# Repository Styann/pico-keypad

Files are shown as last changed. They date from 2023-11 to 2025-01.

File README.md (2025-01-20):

# Anesidora

A 65% keyboard PCB for the Raspberry pi pico made with KiCad 8, and a custom firmware.

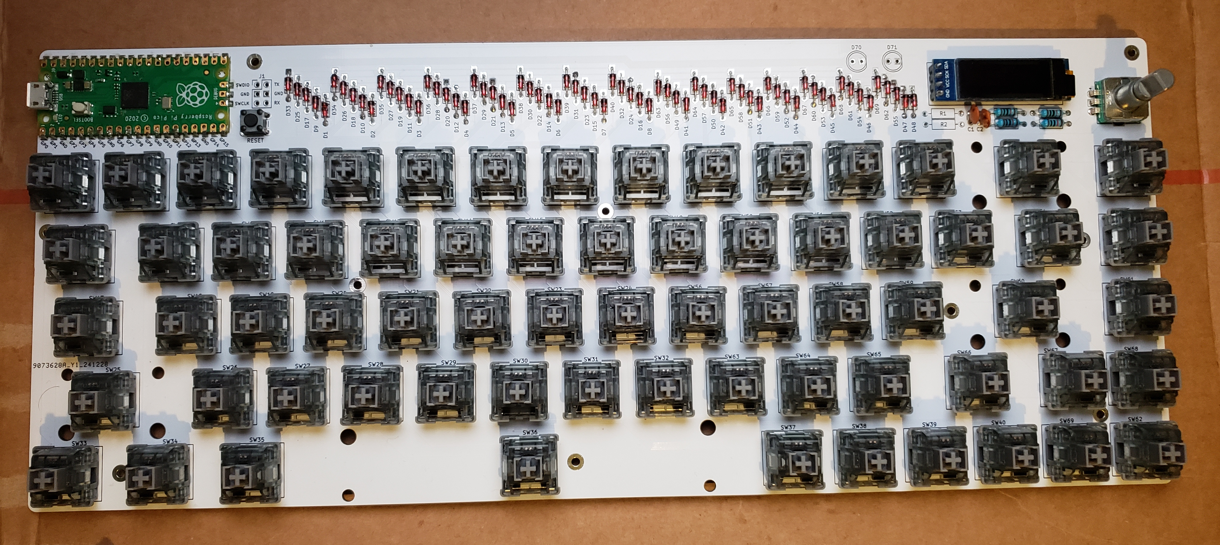
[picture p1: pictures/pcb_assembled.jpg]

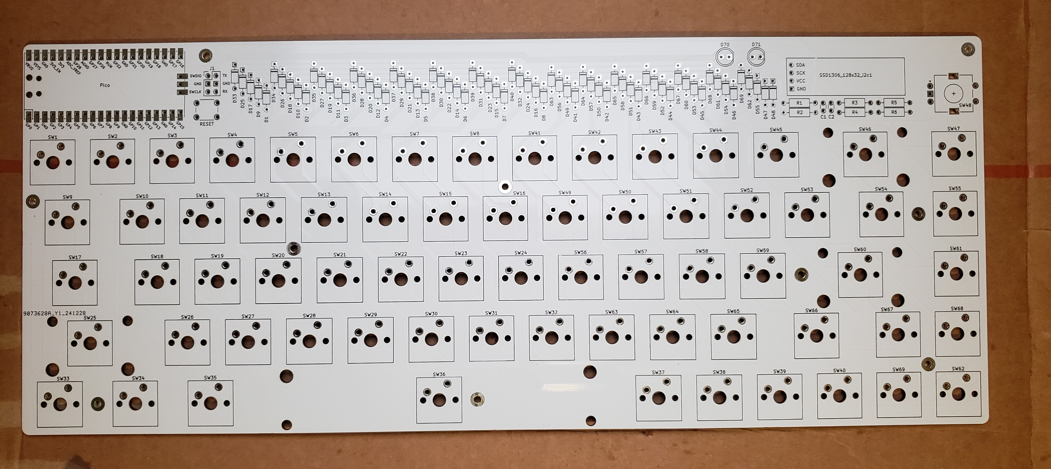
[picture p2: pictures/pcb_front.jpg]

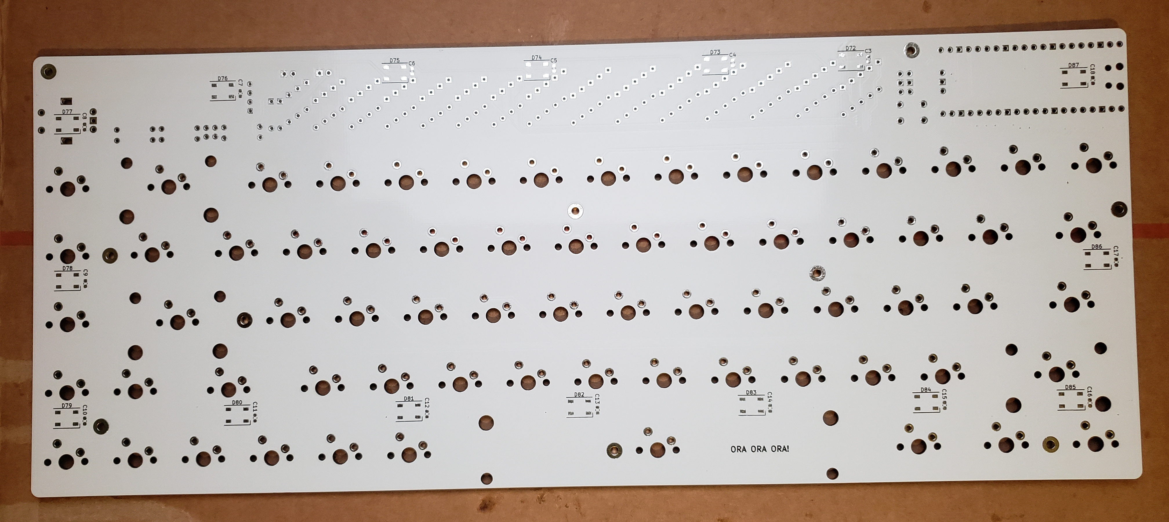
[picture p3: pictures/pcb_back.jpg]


## Assembly

### THT components
- Raspberry Pico
- Keyboard Switches (x68)
- Keyboard Stabilizers
- Rotary Encoder
- Resistors 10KOhm (x4)
- Capacitors 0.1µF (x2)
- Diodes 1N4148 (x69)
- SSD1306 OLED display 128x32
- LEDs (x2)
- Resistors (x2 for LEDs)
- Button
- 2.54mm Male Pin Header 2x6

### SMD components
- leds WS2812B (x16)
- SMD Capacitors 0603 100nF (x16)

## 📦 Build the firmware
1.
Install the pico C/C++ SDK (https://www.raspberrypi.com/documentation/microcontrollers/c_sdk.html)

2.
```sh
export ANESIDORA_PATH=path/to/Anesidora
```

3.
```sh
export PICO_USB_DISK_PATH=path/to/RPI-RP2
```

4.
```sh
./deploy.sh --build --flash
```

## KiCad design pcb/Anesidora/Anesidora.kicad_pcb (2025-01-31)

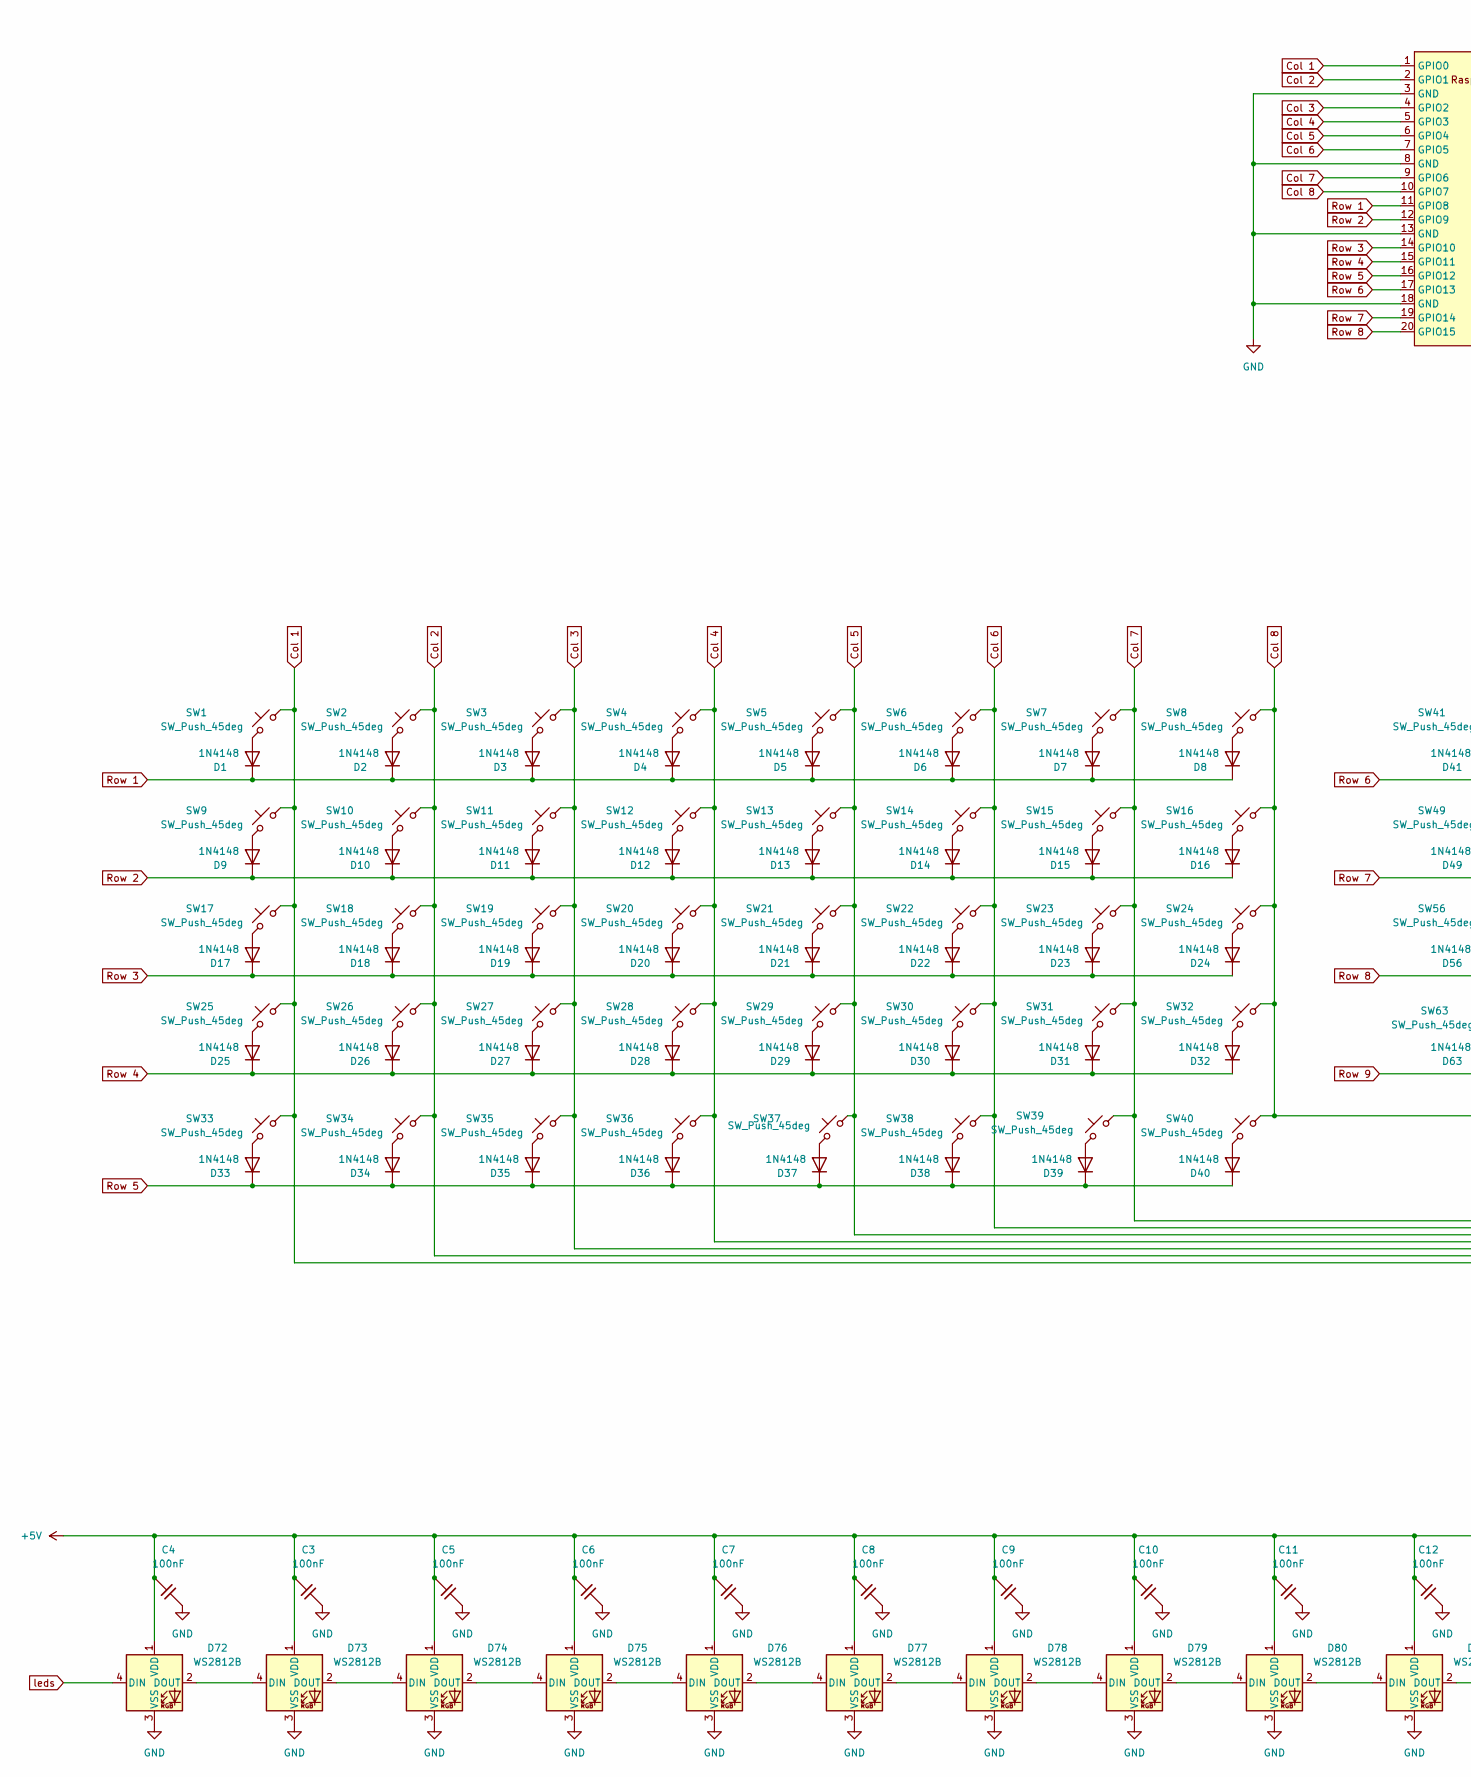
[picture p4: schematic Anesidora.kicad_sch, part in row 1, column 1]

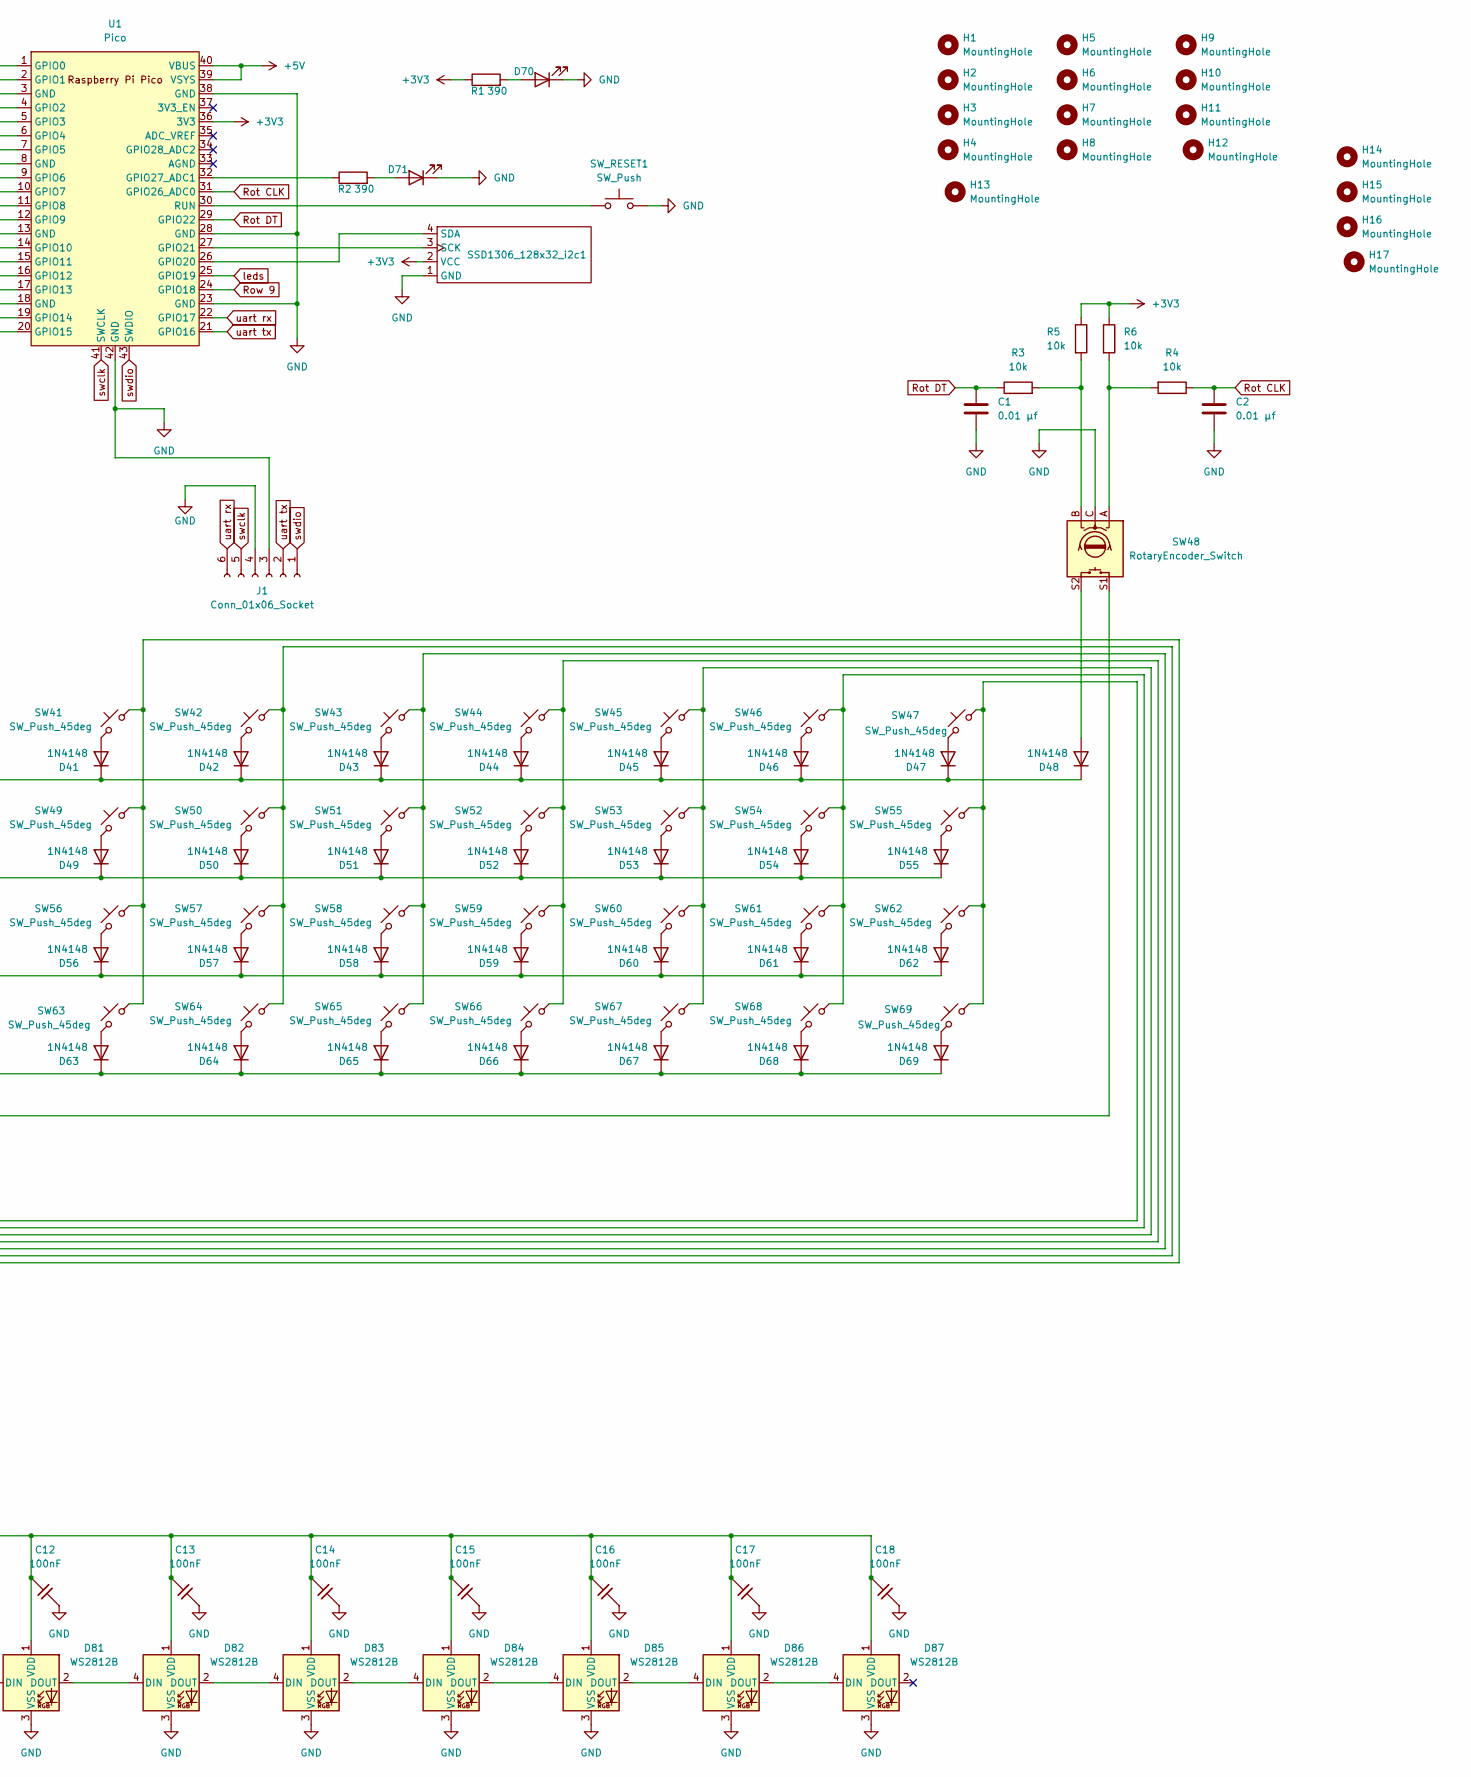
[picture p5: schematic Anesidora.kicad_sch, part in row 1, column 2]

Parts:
C1, C2: 0.01 µf; C_Disc_D3.0mm_W1.6mm_P2.50mm
C3, C4, C5, C6, C7, C8, C9, C10, C11, C12, C13, C14, C15, C16, C17, C18: 100nF; C_0603_1608Metric
D1, D2, D3, D4, D5, D6, D7, D8, D9, D10, D11, D12, D13, D14, D15, D16, D17, D18, D19, D20, D21, D22, D23, D24, D25, D26, D27, D28, D29, D30, D31, D32, D33, D34, D35, D36, D37, D38, D39, D40, D41, D42, D43, D44, D45, D46, D47, D48, D49, D50, D51, D52, D53, D54, D55, D56, D57, D58, D59, D60, D61, D62, D63, D64, D65, D66, D67, D68, D69: 1N4148; D_DO-35_SOD27_P7.62mm_Horizontal
D70, D71: LED; LED_D5.0mm
D72, D73, D74, D75, D76, D77, D78, D79, D80, D81, D82, D83, D84, D85, D86, D87: WS2812B; LED_WS2812B_PLCC4_5.0x5.0mm_P3.2mm
H1, H2, H3, H4, H5, H6, H7, H8, H9, H10, H11, H12, H13, H14, H15, H16, H17: MountingHole; MountingHole_2.2mm_M2_Pad
J1: Conn_01x06_Socket; PinHeader_2x03_P2.54mm_Vertical
R1, R2: 390; R_Axial_DIN0207_L6.3mm_D2.5mm_P10.16mm_Horizontal
R3, R4, R5, R6: 10k; R_Axial_DIN0207_L6.3mm_D2.5mm_P10.16mm_Horizontal
SSD1306_128x32_i2c1: SSD1306_128x32_i2c
SW1, SW2, SW3, SW4, SW5, SW6, SW7, SW8, SW10, SW11, SW12, SW13, SW14, SW15, SW16, SW18, SW19, SW20, SW21, SW22, SW23, SW24, SW26, SW27, SW28, SW29, SW30, SW31, SW32, SW37, SW38, SW39, SW40, SW41, SW42, SW43, SW44, SW45, SW47, SW49, SW50, SW51, SW52, SW53, SW55, SW56, SW57, SW58, SW59, SW61, SW62, SW63, SW64, SW65, SW67, SW68, SW69: SW_Push_45deg; SW_Cherry_MX_PCB_1.00u
SW9, SW54: SW_Push_45deg; SW_Cherry_MX_PCB_1.50u
SW17, SW66: SW_Push_45deg; SW_Cherry_MX_PCB_1.75u
SW25, SW60: SW_Push_45deg; SW_Cherry_MX_PCB_2.25u
SW33, SW34, SW35: SW_Push_45deg; SW_Cherry_MX_PCB_1.25u
SW36: SW_Push_45deg; SW_Cherry_MX_PCB_6.25u
SW46: SW_Push_45deg; SW_Cherry_MX_PCB_2.00u
SW48: RotaryEncoder_Switch; RotaryEncoder_Alps_EC11E-Switch_Vertical_H20mm
SW_RESET1: SW_Push; SW_PUSH_6mm
U1: Pico; RPi_Pico_SMD_TH

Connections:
+3V3: R1.1, R5.1, R6.1, SSD1306_128x32_i2c1.2 (VCC), U1.36 (3V3); also elsewhere on the board
+5V: C3.2, C4.2, C5.2, C6.2, C7.2, C8.2, C9.2, C10.2, C11.2, C12.2, C13.2, C14.2, C15.2, C16.2, C17.2, C18.2, D72.1 (VDD), D73.1 (VDD), D74.1 (VDD), D75.1 (VDD), D76.1 (VDD), D77.1 (VDD), D78.1 (VDD), D79.1 (VDD), D80.1 (VDD), D81.1 (VDD), D82.1 (VDD), D83.1 (VDD), D84.1 (VDD), D85.1 (VDD), D86.1 (VDD), D87.1 (VDD), U1.39 (VSYS), U1.40 (VBUS); also elsewhere on the board
Col 1: SW1.2, SW9.2, SW17.2, SW25.2, SW33.2, SW41.2, SW49.2, SW56.2, SW63.2, U1.1 (GPIO0); also elsewhere on the board
Col 2: SW2.2, SW10.2, SW18.2, SW26.2, SW34.2, SW42.2, SW50.2, SW57.2, SW64.2, U1.2 (GPIO1); also elsewhere on the board
Col 3: SW3.2, SW11.2, SW19.2, SW27.2, SW35.2, SW43.2, SW51.2, SW58.2, SW65.2, U1.4 (GPIO2); also elsewhere on the board
Col 4: SW4.2, SW12.2, SW20.2, SW28.2, SW36.2, SW44.2, SW52.2, SW59.2, SW66.2, U1.5 (GPIO3); also elsewhere on the board
Col 5: SW5.2, SW13.2, SW21.2, SW29.2, SW37.2, SW45.2, SW53.2, SW60.2, SW67.2, U1.6 (GPIO4); also elsewhere on the board
Col 6: SW6.2, SW14.2, SW22.2, SW30.2, SW38.2, SW46.2, SW54.2, SW61.2, SW68.2, U1.7 (GPIO5); also elsewhere on the board
Col 7: SW7.2, SW15.2, SW23.2, SW31.2, SW39.2, SW47.2, SW55.2, SW62.2, SW69.2, U1.9 (GPIO6); also elsewhere on the board
Col 8: SW8.2, SW16.2, SW24.2, SW32.2, SW40.2, SW48.S1, U1.10 (GPIO7); also elsewhere on the board
GND: C1.2, C2.2, C3.1, C4.1, C5.1, C6.1, C7.1, C8.1, C9.1, C10.1, C11.1, C12.1, C13.1, C14.1, C15.1, C16.1, C17.1, C18.1, D70.1 (K), D71.1 (K), D72.3 (VSS), D73.3 (VSS), D74.3 (VSS), D75.3 (VSS), D76.3 (VSS), D77.3 (VSS), D78.3 (VSS), D79.3 (VSS), D80.3 (VSS), D81.3 (VSS), D82.3 (VSS), D83.3 (VSS), D84.3 (VSS), D85.3 (VSS), D86.3 (VSS), D87.3 (VSS), J1.3, J1.4, SSD1306_128x32_i2c1.1 (GND), SW48.C, SW_RESET1.2, U1.3 (GND), U1.8 (GND), U1.13 (GND), U1.18 (GND), U1.23 (GND), U1.28 (GND), U1.38 (GND), U1.42 (GND); also elsewhere on the board
unnamed: D1.2 (A), SW1.1
unnamed: D2.2 (A), SW2.1
unnamed: D3.2 (A), SW3.1
unnamed: D4.2 (A), SW4.1
unnamed: D5.2 (A), SW5.1
unnamed: D6.2 (A), SW6.1
unnamed: D7.2 (A), SW7.1
unnamed: D8.2 (A), SW8.1
unnamed: D9.2 (A), SW9.1
unnamed: D10.2 (A), SW10.1
unnamed: D11.2 (A), SW11.1
unnamed: D12.2 (A), SW12.1
unnamed: D13.2 (A), SW13.1
unnamed: D14.2 (A), SW14.1
unnamed: D15.2 (A), SW15.1
unnamed: D16.2 (A), SW16.1
unnamed: D17.2 (A), SW17.1
unnamed: D18.2 (A), SW18.1
unnamed: D19.2 (A), SW19.1
unnamed: D20.2 (A), SW20.1
unnamed: D21.2 (A), SW21.1
unnamed: D22.2 (A), SW22.1
unnamed: D23.2 (A), SW23.1
unnamed: D24.2 (A), SW24.1
unnamed: D25.2 (A), SW25.1
unnamed: D26.2 (A), SW26.1
unnamed: D27.2 (A), SW27.1
unnamed: D28.2 (A), SW28.1
unnamed: D29.2 (A), SW29.1
unnamed: D30.2 (A), SW30.1
unnamed: D31.2 (A), SW31.1
unnamed: D32.2 (A), SW32.1
unnamed: D33.2 (A), SW33.1
unnamed: D34.2 (A), SW34.1
unnamed: D35.2 (A), SW35.1
unnamed: D36.2 (A), SW36.1
unnamed: D37.2 (A), SW37.1
unnamed: D38.2 (A), SW38.1
unnamed: D39.2 (A), SW39.1
unnamed: D40.2 (A), SW40.1
unnamed: D41.2 (A), SW41.1
unnamed: D42.2 (A), SW42.1
unnamed: D43.2 (A), SW43.1
unnamed: D44.2 (A), SW44.1
unnamed: D45.2 (A), SW45.1
unnamed: D46.2 (A), SW46.1
unnamed: D47.2 (A), SW47.1
unnamed: D48.2 (A), SW48.S2
unnamed: D49.2 (A), SW49.1
unnamed: D50.2 (A), SW50.1
unnamed: D51.2 (A), SW51.1
unnamed: D52.2 (A), SW52.1
unnamed: D53.2 (A), SW53.1
unnamed: D54.2 (A), SW54.1
unnamed: D55.2 (A), SW55.1
unnamed: D56.2 (A), SW56.1
unnamed: D57.2 (A), SW57.1
unnamed: D58.2 (A), SW58.1
unnamed: D59.2 (A), SW59.1
unnamed: D60.2 (A), SW60.1
unnamed: D61.2 (A), SW61.1
unnamed: D62.2 (A), SW62.1
unnamed: D63.2 (A), SW63.1
unnamed: D64.2 (A), SW64.1
unnamed: D65.2 (A), SW65.1
unnamed: D66.2 (A), SW66.1
unnamed: D67.2 (A), SW67.1
unnamed: D68.2 (A), SW68.1
unnamed: D69.2 (A), SW69.1
unnamed: D70.2 (A), R1.2
unnamed: D71.2 (A), R2.2
unnamed: D72.2 (DOUT), D73.4 (DIN)
unnamed: D73.2 (DOUT), D74.4 (DIN)
unnamed: D74.2 (DOUT), D75.4 (DIN)
unnamed: D75.2 (DOUT), D76.4 (DIN)
unnamed: D76.2 (DOUT), D77.4 (DIN)
unnamed: D77.2 (DOUT), D78.4 (DIN)
unnamed: D78.2 (DOUT), D79.4 (DIN)
unnamed: D79.2 (DOUT), D80.4 (DIN)
unnamed: D80.2 (DOUT), D81.4 (DIN)
unnamed: D81.2 (DOUT), D82.4 (DIN)
unnamed: D82.2 (DOUT), D83.4 (DIN)
unnamed: D83.2 (DOUT), D84.4 (DIN)
unnamed: D84.2 (DOUT), D85.4 (DIN)
unnamed: D85.2 (DOUT), D86.4 (DIN)
unnamed: D86.2 (DOUT), D87.4 (DIN)
unnamed: R3.2, R5.2, SW48.B
unnamed: R4.2, R6.2, SW48.A
unnamed 99: SSD1306_128x32_i2c1.3 (SCK), U1.27 (GPIO21); also elsewhere on the board
unnamed 100: SSD1306_128x32_i2c1.4 (SDA), U1.26 (GPIO20); also elsewhere on the board
unnamed: SW_RESET1.1, U1.30 (RUN)
unnamed 102: R2.1, U1.32 (GPIO27_ADC1); also elsewhere on the board
Rot CLK: C2.1, R4.1, U1.31 (GPIO26_ADC0); also elsewhere on the board
Rot DT: C1.1, R3.1, U1.29 (GPIO22); also elsewhere on the board
Row 1: D1.1 (K), D2.1 (K), D3.1 (K), D4.1 (K), D5.1 (K), D6.1 (K), D7.1 (K), D8.1 (K), U1.11 (GPIO8); also elsewhere on the board
Row 2: D9.1 (K), D10.1 (K), D11.1 (K), D12.1 (K), D13.1 (K), D14.1 (K), D15.1 (K), D16.1 (K), U1.12 (GPIO9); also elsewhere on the board
Row 3: D17.1 (K), D18.1 (K), D19.1 (K), D20.1 (K), D21.1 (K), D22.1 (K), D23.1 (K), D24.1 (K), U1.14 (GPIO10); also elsewhere on the board
Row 4: D25.1 (K), D26.1 (K), D27.1 (K), D28.1 (K), D29.1 (K), D30.1 (K), D31.1 (K), D32.1 (K), U1.15 (GPIO11); also elsewhere on the board
Row 5: D33.1 (K), D34.1 (K), D35.1 (K), D36.1 (K), D37.1 (K), D38.1 (K), D39.1 (K), D40.1 (K), U1.16 (GPIO12); also elsewhere on the board
Row 6: D41.1 (K), D42.1 (K), D43.1 (K), D44.1 (K), D45.1 (K), D46.1 (K), D47.1 (K), D48.1 (K), U1.17 (GPIO13); also elsewhere on the board
Row 7: D49.1 (K), D50.1 (K), D51.1 (K), D52.1 (K), D53.1 (K), D54.1 (K), D55.1 (K), U1.19 (GPIO14); also elsewhere on the board
Row 8: D56.1 (K), D57.1 (K), D58.1 (K), D59.1 (K), D60.1 (K), D61.1 (K), D62.1 (K), U1.20 (GPIO15); also elsewhere on the board
Row 9: D63.1 (K), D64.1 (K), D65.1 (K), D66.1 (K), D67.1 (K), D68.1 (K), D69.1 (K), U1.24 (GPIO18); also elsewhere on the board
leds: D72.4 (DIN), U1.25 (GPIO19); also elsewhere on the board
swclk: J1.5, U1.41 (SWCLK); also elsewhere on the board
swdio: J1.1, U1.43 (SWDIO); also elsewhere on the board
uart rx: J1.6, U1.22 (GPIO17); also elsewhere on the board
uart tx: J1.2, U1.21 (GPIO16); also elsewhere on the board

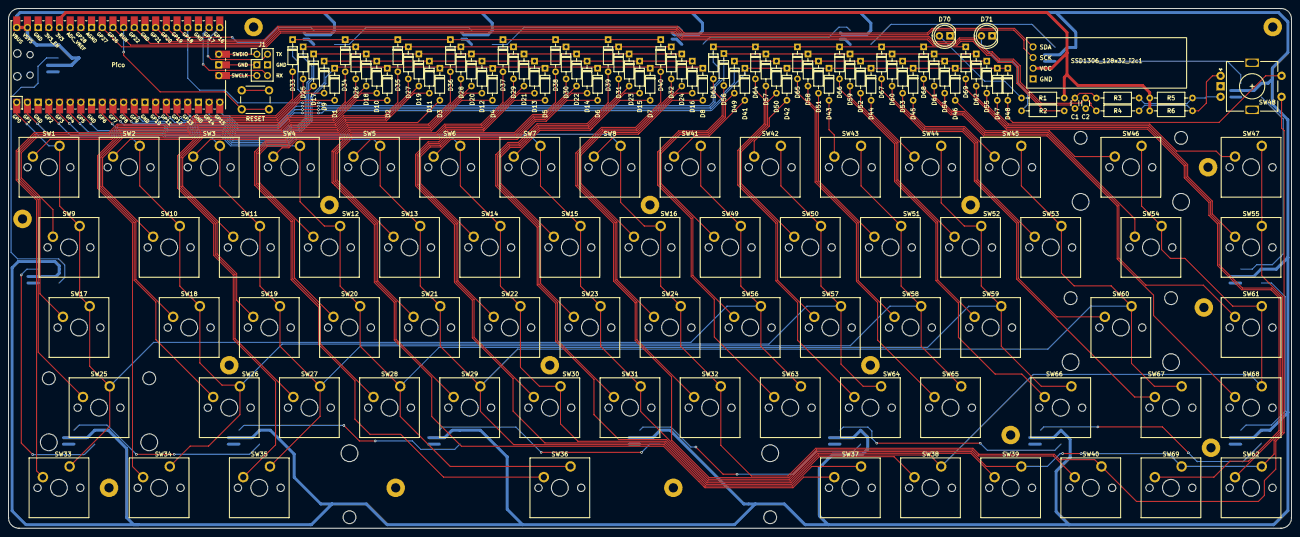
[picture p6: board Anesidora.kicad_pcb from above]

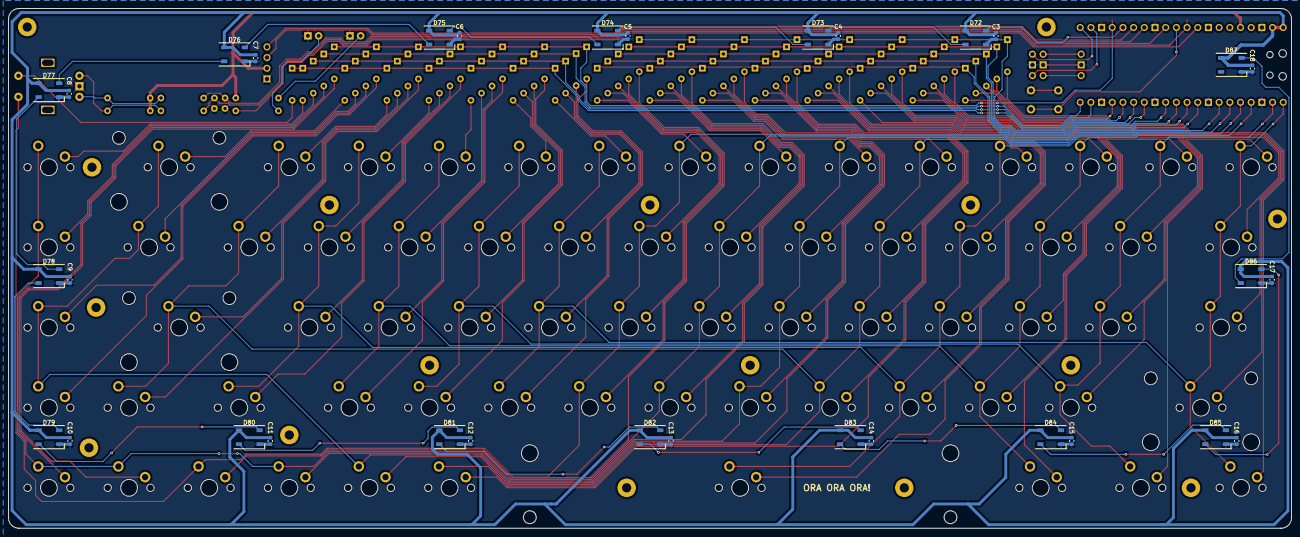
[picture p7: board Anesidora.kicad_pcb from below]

Board: 2 copper layers, 305.0 x 123.5 mm, 200 parts (32 on the bottom side), 119 nets.

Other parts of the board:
Pico: Pico; RPi_Pico_SMD_TH
RESET: SW_Push; SW_PUSH_6mm

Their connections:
+3V3: Pico.36 (3V3); also elsewhere on the board
+5V: Pico.39 (VSYS), Pico.40 (VBUS); also elsewhere on the board
Col 1: Pico.1 (GPIO0); also elsewhere on the board
Col 2: Pico.2 (GPIO1); also elsewhere on the board
Col 3: Pico.4 (GPIO2); also elsewhere on the board
Col 4: Pico.5 (GPIO3); also elsewhere on the board
Col 5: Pico.6 (GPIO4); also elsewhere on the board
Col 6: Pico.7 (GPIO5); also elsewhere on the board
Col 7: Pico.9 (GPIO6); also elsewhere on the board
Col 8: Pico.10 (GPIO7); also elsewhere on the board
GND: Pico.3 (GND), Pico.8 (GND), Pico.13 (GND), Pico.18 (GND), Pico.23 (GND), Pico.28 (GND), Pico.38 (GND), Pico.42 (GND), RESET.2; also elsewhere on the board
unnamed 99: Pico.27 (GPIO21); also elsewhere on the board
unnamed 100: Pico.26 (GPIO20); also elsewhere on the board
unnamed 102: Pico.32 (GPIO27_ADC1); also elsewhere on the board
unnamed: Pico.30 (RUN), RESET.1
Rot CLK: Pico.31 (GPIO26_ADC0); also elsewhere on the board
Rot DT: Pico.29 (GPIO22); also elsewhere on the board
Row 1: Pico.11 (GPIO8); also elsewhere on the board
Row 2: Pico.12 (GPIO9); also elsewhere on the board
Row 3: Pico.14 (GPIO10); also elsewhere on the board
Row 4: Pico.15 (GPIO11); also elsewhere on the board
Row 5: Pico.16 (GPIO12); also elsewhere on the board
Row 6: Pico.17 (GPIO13); also elsewhere on the board
Row 7: Pico.19 (GPIO14); also elsewhere on the board
Row 8: Pico.20 (GPIO15); also elsewhere on the board
Row 9: Pico.24 (GPIO18); also elsewhere on the board
leds: Pico.25 (GPIO19); also elsewhere on the board
swclk: Pico.41 (SWCLK); also elsewhere on the board
swdio: Pico.43 (SWDIO); also elsewhere on the board
uart rx: Pico.22 (GPIO17); also elsewhere on the board
uart tx: Pico.21 (GPIO16); also elsewhere on the board

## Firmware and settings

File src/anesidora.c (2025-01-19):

/**
 * @author Styann
 */

#include <stdio.h>

#include "pico/stdlib.h"
#include "pico/multicore.h"
#include "hardware/gpio.h"
#include "hardware/timer.h"
#include "hardware/pwm.h"
#include "hardware/structs/usb.h"
#include "hardware/uart.h"

#include "../lib/pico_extra/pico_extra.h"
#include "../lib/usb/usb.h"
#include "../lib/usb/usb_hid.h"
#include "../lib/debounce/debounce.h"
#include "../lib/keyboard/keyboard.h"
#include "../lib/rotary_encoder/rotary_encoder.h"
#include "../lib/graphics/color.h"
#include "../lib/ws2812b/ws2812b.h"
#include "../lib/ssd1306/ssd1306.h"
#include "../lib/led/led.h"

#include "../include/bongocat.h"
#include "../include/usb_descriptors.h"

#define USE_CAPSLOCK_LED
#define USE_KEYBOARD
#define USE_KNOB
#define USE_WS2812B
#define USE_SSD1306

enum multicore_flags {
    BONGOCAT_TAP_FLAG = 0xC0,
    BONGOCAT_PAWS_UP_FLAG,
    USB_SUSPEND_FLAG,
    USB_RESUME_FLAG,
    LEDS_CHANGE_COLOR
};

volatile uint8_t modifiers = 0b00000000;
volatile bool is_fn_pressed = false;

void ep0_out_handler(uint8_t *buf, uint16_t len);
void ep0_in_handler(uint8_t *buf, uint16_t len);
void ep1_in_handler(uint8_t *buf, uint16_t len);

usb_device_t pico = {
    .addr = 0x00,
    .should_set_addr = false,
    .suspended = false,
    .configured = false,
    .endpoints = {
        {
            .descriptor = &ep0_in_descriptor,
            .handler = &ep0_in_handler,
            .endpoint_control = NULL, // NA for EP0,
            .buffer_control = &usb_dpram->ep_buf_ctrl[0].in,
            // EP0 in and out share a data buffer
            .data_buffer = &usb_dpram->ep0_buf_a[0],
        },
        {
            .descriptor = &ep0_out_descriptor,
            .handler = &ep0_out_handler,
            .endpoint_control = NULL, // NA for EP0
            .buffer_control = &usb_dpram->ep_buf_ctrl[0].out,
            // EP0 in and out share a data buffer
            .data_buffer = &usb_dpram->ep0_buf_a[0],
        },
        {
            .descriptor = &ep1_in_descriptor,
            .handler = &ep1_in_handler,
            .endpoint_control = &usb_dpram->ep_ctrl[0].in,
            .buffer_control = &usb_dpram->ep_buf_ctrl[1].in,
            .data_buffer = &usb_dpram->epx_data[0 * 64]
        }
    },
    .device_descriptor = &device_descriptor,
    .configuration_descriptor = &config_descriptor,
    .language_descriptor = &language_descriptor,
    .vendor = "Seegson Electronics",
    .product = "USB Keyboard",
};

void ep0_out_handler(uint8_t *buf, uint16_t len) {

}

void ep0_in_handler(uint8_t *buf, uint16_t len) {
    if (pico.should_set_addr) {
        // Set actual device address in hardware
        usb_hw->dev_addr_ctrl = pico.addr;
        pico.should_set_addr = false;
    } else {
        // Receive a zero length status packet from the host on EP0 OUT
        usb_xfer(usb_get_endpoint(&pico, USB_DIR_OUT), NULL, 0);
    }
}

void ep1_in_handler(uint8_t *buf, uint16_t len) {

}

struct usb_hid_interface keyboard_interface = {
    .interface_descriptor = &keyboard_interface_descriptor,
    .hid_descriptor = &keyboard_hid_descriptor,
    .endpoint = &pico.endpoints[2]
};

void usb_handle_hid_report(const uint16_t bDescriptorIndex, const uint16_t wInterfaceNumber, const uint16_t wDescriptorLength) {
    switch (wInterfaceNumber) {
        case 0:
            usb_xfer_ep0_in(&pico, (uint8_t *)keyboard_report_descriptor, sizeof(keyboard_report_descriptor));
            break;
    }
}

void usb_handle_config_descriptor(usb_device_t *const device, const uint16_t wLength) {
    uint8_t buffer[128];
    uint8_t *buffer_ptr = buffer;

    memcpy((void *)buffer_ptr, device->configuration_descriptor, device->configuration_descriptor->bLength);
    buffer_ptr += device->configuration_descriptor->bLength;

    if (wLength >= device->configuration_descriptor->wTotalLength) {
        buffer_ptr += hid_interface_cpy(buffer_ptr, &keyboard_interface);
    }

    usb_xfer_ep0_in(device, buffer, buffer_ptr - buffer);
}

struct usb_endpoint *const keyboard_ep = &pico.endpoints[2];

/**
 * @brief USB interrupt handler
 */
void isr_usbctrl(void) {
    isr_usbctrl_task(&pico);
}

#ifdef USE_CAPSLOCK_LED
led_t capslock_led = { .pin = GPIO27, .state = LOW };
#endif

#ifdef USE_SSD1306
ssd1306_t output = {
    .pin_SCK = GPIO21,
    .pin_SDA = GPIO20,
    .i2c_inst = i2c0
};
#endif

#ifdef USE_WS2812B
#define NUM_LEDS 16

struct grb leds_buffer[NUM_LEDS];
uint8_t leds_spi_buffer[NUM_LEDS][bitsizeof(struct grb)];

struct ws2812b led_strip = {
    .pin_Din = GPIO19,
    .spi_inst = spi0,
    .num_leds = NUM_LEDS,
    .leds_buffer = leds_buffer,
    .spi_buffer = &leds_spi_buffer[0][0],
};
#endif

#ifdef USE_KNOB
void knob_cw_callback(uint32_t state);
void knob_ccw_callback(uint32_t state);

rotary_encoder_t volume_knob = {
    .pin_DT = GPIO22,
    .pin_CLK = GPIO26,
    .cw_callback = &knob_cw_callback,
    .ccw_callback = &knob_ccw_callback
};

void knob_cw_callback(uint32_t state) {
    usb_send_consumer_control(keyboard_ep, CC_VOLUME_INCREMENT);
}

void knob_ccw_callback(uint32_t state) {
    usb_send_consumer_control(keyboard_ep, CC_VOLUME_DECREMENT);
}
#endif

#ifdef USE_KEYBOARD
#define DEBOUNCE_MS 10
#define LAYOUT_COLUMN_SIZE 8
#define LAYOUT_ROW_SIZE 9

const uint8_t columns_pins[LAYOUT_COLUMN_SIZE] = { GPIO0, GPIO1, GPIO2, GPIO3, GPIO4, GPIO5, GPIO6, GPIO7 };
const uint8_t rows_pins[LAYOUT_ROW_SIZE] = { GPIO8, GPIO9, GPIO10, GPIO11, GPIO12, GPIO13, GPIO14, GPIO15, GPIO18 };

const uint8_t layout[LAYOUT_ROW_SIZE][LAYOUT_COLUMN_SIZE] = {
    { KC_ESCAPE,     KC_1,        KC_2,         KC_3,                   KC_4,                    KC_5,         KC_6,           KC_7          },
    { KC_TAB,        KC_Q,        KC_W,         KC_E,                   KC_R,                    KC_T,         KC_Y,           KC_U          },
    { KC_CAPS_LOCK,  KC_A,        KC_S,         KC_D,                   KC_F,                    KC_G,         KC_H,           KC_J          },
    { KC_SHIFT_LEFT, KC_Z,        KC_X,         KC_C,                   KC_V,                    KC_B,         KC_N,           KC_M          },
    { KC_CTRL_LEFT,  KC_GUI_LEFT, KC_ALT_LEFT,  KC_SPACE,               KC_ALT_RIGHT,            KC_FN,        KC_CTRL_RIGHT,  KC_ARROW_LEFT },
    { KC_8,          KC_9,        KC_0,         KC_MINUS,               KC_EQUAL,                KC_BACKSPACE, KC_GRAVE,       KC_PAUSE      },
    { KC_I,          KC_O,        KC_P,         KC_SQUARE_BRACKET_LEFT, KC_SQUARE_BRACKET_RIGHT, KC_BACKSLASH, KC_DELETE,      KC_NONE       },
    { KC_K,          KC_L,        KC_SEMICOLON, KC_APOSTROPHE,          KC_ENTER,                KC_HOME,      KC_ARROW_RIGHT, KC_NONE       },
    { KC_COMMA,      KC_PERIOD,   KC_SLASH,     KC_SHIFT_RIGHT,         KC_ARROW_UP,             KC_END,       KC_ARROW_DOWN , KC_NONE       },
};

keyboard_matrix_t keyboard_matrix = {
    .layout = &layout[0][0],
    .columns_pins = columns_pins,
    .rows_pins = rows_pins,
    .row_length = LAYOUT_ROW_SIZE,
    .column_length = LAYOUT_COLUMN_SIZE
};

bool macro_task(struct usb_keyboard_report *report) {
    modifiers = report->modifiers;

    if (report->keycodes[0] == KC_FN && report->keycodes[1] == KC_L) {
        multicore_fifo_drain();
        multicore_fifo_push_blocking(LEDS_CHANGE_COLOR);
        return true;
    }

    return false;
}

void keyboard_task(void) {
    static uint32_t timer = 0;

    if (debounce(&timer, DEBOUNCE_MS)) {
        static bool can_release = false;
        static struct usb_keyboard_report previous_report = { 0x01, 0, 0, { 0, 0, 0, 0, 0, 0 }};

        struct usb_keyboard_report keyboard_report = { 0x01, 0, 0, { 0, 0, 0, 0, 0, 0 } };
        const bool is_empty = keyboard_matrix_scan(&keyboard_matrix, &keyboard_report);

        // if there is a change between actual and previous report
        if (!keyboard_report_cmp(&keyboard_report, &previous_report)) {
            if (!macro_task(&keyboard_report)) {
                if (!is_empty) {
                    usb_send_keyboard_report(keyboard_ep, &keyboard_report);
                    can_release = true;

                    #ifdef USE_SSD1306
                    multicore_fifo_drain();
                    multicore_fifo_push_blocking(BONGOCAT_TAP_FLAG);
                    #endif
                }
                else if (can_release) {
                    release_keyboard(keyboard_ep);
                    can_release = false;

                    #ifdef USE_SSD1306
                    multicore_fifo_drain();
                    multicore_fifo_push_blocking(BONGOCAT_PAWS_UP_FLAG);
                    #endif
                }
            }

            previous_report = keyboard_report;
        }
    }
}
#endif

void main_core1(void) {
    const struct grb colors[] = {
        grb(255, 0, 0),
        grb(251, 255, 0), // yellow
        grb(39, 238, 255), // magenta
        grb(255, 39, 255), // cyan
        grb(128, 255, 0), // orange
        grb(0, 0, 0)
    };

    core1_resume: {
        uint32_t multicore_flag = 0;

        #ifdef USE_SSD1306
        ssd1306_init(&output, 400000);
        ssd1306_write_all(&output, bongocat_paws_up);
        uint32_t bongocat_paw_state = 0;
        uint32_t bongocat_timer = 0;
        #endif

        #ifdef USE_WS2812B
        uint8_t color_index = 0;
        ws2812b_init(&led_strip);
        ws2812b_set_all(&led_strip, colors[color_index]);
        ws2812b_write(&led_strip);
        #endif

        while (true) {
            if (multicore_fifo_rvalid()) {
                multicore_flag = multicore_fifo_pop_blocking();
            }

            if (multicore_flag == USB_SUSPEND_FLAG) {
                multicore_flag = 0;
                goto core1_suspend;
            }

            #ifdef USE_SSD1306
            switch (multicore_flag) {
                case BONGOCAT_TAP_FLAG:
                    ssd1306_write_all(&output, bongocat_paw_down[bongocat_paw_state]);
                    bongocat_paw_state ^= 1;
                    multicore_flag = 0;
                    break;
                case BONGOCAT_PAWS_UP_FLAG:
                    ssd1306_write_all(&output, bongocat_paws_up);
                    multicore_flag = 0;
                    break;
            }
            #endif

            #ifdef USE_WS2812B
            switch (multicore_flag) {
                case LEDS_CHANGE_COLOR:
                    color_index++;
                    if (color_index > (lengthof(colors) - 1)) color_index = 0;

                    ws2812b_set_all(&led_strip, colors[color_index]);
                    ws2812b_write(&led_strip);

                    multicore_flag = 0;
                    break;
            }
            #endif
        }
    }

    core1_suspend: {
        #ifdef USE_SSD1306
        ssd1306_deinit(&output);
        #endif

        #ifdef USE_WS2812B
        ws2812b_set_all(&led_strip, grb(0, 0, 0));
        ws2812b_write(&led_strip);
        ws2812b_deinit(&led_strip);
        #endif

        while (true) {
            uint32_t flag = (multicore_fifo_rvalid()) ? multicore_fifo_pop_blocking() : 0;

            if (flag == USB_RESUME_FLAG) {
                goto core1_resume;
            }
        }
    }
}

void set_report_callback(volatile uint8_t *buf, uint16_t len) {
    release_keyboard(keyboard_ep);

    // #ifdef USE_CAPSLOCK_LED
    // led_toggle(&capslock_led);
    // #endif

    // char str[2];

    // if (len == 1) {
        // usb_control_xfer(&pico, NULL, 0);
        // sprintf(str, "%d", len);
        // uart_puts(uart0, str);
    // }
    // else {
        // usb_control_xfer(&pico, NULL, 0);
        // sprintf(str, "%d", len);
        // uart_puts(uart0, str);
    // }
}

void usb_suspend_callback(void) {
    multicore_fifo_drain();
    multicore_fifo_push_blocking(USB_SUSPEND_FLAG);
}

void usb_resume_callback(void) {
    multicore_fifo_drain();
    multicore_fifo_push_blocking(USB_RESUME_FLAG);
}

int main(void) {
    built_in_led_init();
    built_in_led_on();

    uart_init(uart0, 115200);
    gpio_set_function(GPIO16, UART_FUNCSEL_NUM(uart0, GPIO16));
    gpio_set_function(GPIO17, UART_FUNCSEL_NUM(uart0, GPIO17));
    uart_puts(uart0, "initing pico !\n");

    #ifdef USE_CAPSLOCK_LED
    led_init(&capslock_led);
    #endif

    usb_device_init(&pico);

    while (!pico.configured) {
        tight_loop_contents();
    }

    built_in_led_off();

    multicore_launch_core1(&main_core1);

    #ifdef USE_KEYBOARD
    keyboard_matrix_init(&keyboard_matrix);
    #endif

    #ifdef USE_KNOB
    rotary_encoder_init(&volume_knob, false);
    #endif

    while (true) {
        #ifdef USE_KEYBOARD
        keyboard_task();
        #endif

        #ifdef USE_KNOB
        rotary_encoder_task(&volume_knob);
        #endif
    }

    return 0;
}

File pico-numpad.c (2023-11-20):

#include <stdio.h>

#include "pico/stdlib.h"
#include "pico/binary_info.h"
#include "pico/multicore.h"
#include "hardware/gpio.h"
#include "hardware/adc.h"

#include "tusb.h"
//#include "bsp/board.h"
#include "lib/tinyusb/usb_descriptors.h"

#include "Keys/Keys.h"


#define POTENTIOMETER_PIN 1
#define LED_PIN 15
#define DEFAULT_LED_PIN 25

bool keyboard_timer_callback(struct repeating_timer *t);

int main(void) {   
    
    stdio_init_all();
    tusb_init();
    keys_init();
    
    adc_init();
    adc_gpio_init(1);
    adc_select_input(0);
    int led_state = 0;

    struct repeating_timer keyboard_timer;

    add_repeating_timer_ms(
        10, //10ms
        keyboard_timer_callback,
        NULL,
        &keyboard_timer
    );

    gpio_init(LED_PIN);
    gpio_set_dir(LED_PIN, GPIO_OUT);

    gpio_init(POTENTIOMETER_PIN);
    gpio_set_dir(POTENTIOMETER_PIN, GPIO_IN);

    while(true){
        tud_task();

        long result = (float)adc_read() / 10.23;
        if(result >= 50){
            led_state = 0;
        }else if(result < 50){
            led_state = 1;  
        } 
        gpio_put(LED_PIN, led_state);
    }
    
    return 0;
}

bool keyboard_timer_callback(struct repeating_timer *t){
    if(tud_suspended()){
        tud_remote_wakeup();
    }
    else if (tud_hid_ready()){
        send_keyboard_report();
    }

    return true;
}




// TinyUSB HID callbacks

uint16_t tud_hid_get_report_cb(uint8_t instance, uint8_t report_id, hid_report_type_t report_type, uint8_t *buffer, uint16_t reqlen){
    return 0;
}

void tud_hid_set_report_cb(uint8_t instance, uint8_t report_id, hid_report_type_t report_type, uint8_t const *buffer, uint16_t bufsize){

}

void tud_hid_report_complete_cb(uint8_t instance, uint8_t const *report, uint16_t len) {}


// TinyUSB Device callbacks

void tud_cdc_line_state_cb(uint8_t itf, bool dtr, bool rts) {}

void tud_mount_cb() {}

void tud_unmount_cb() {}

void tud_suspend_cb(bool remote_wakeup_en) {}

void tud_resume_cb() {}

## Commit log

2024-01-07 starting to write my own usb driver
2024-01-14 add HID REPORT and SET_IDLE request handling, add led for debugging
2024-01-16 add prototypes, create usb_hid.h, rename Keys to keys
2024-01-16 add sending hid keyboard report from device to host, and some little fix
    [keys.c, layout.h]
2024-02-05 add is_key_pressed and is_keyboard_report_empty function, add toggle switch, add great packet transfer (bigger than the buffer size) , start consumer control handling.
2024-02-11 add possibility to make shortcut, break scan matrix loop when report is full, fix ghosting, delete keyboard_key_t
    [keys.c, layout.h]
2024-02-21 add rgb led strip, update README, remove hid task timer
2024-03-03 remove timer, add consumer control in keyboard report, add leds in usb_hid
2024-04-01 add rotary encode, leds indicator, rgb leds
2024-04-03 rotary encoder using interrutps, remove led_indicator directories
2024-04-09 remake circuit diagram, add hw040 and ws2812b drivers
2024-04-14 leds works, rename long name with this
2024-04-29 +fix report spamming, add conditional preprocessor
    [layout.h]
2024-05-09 + joystick and button api, arcade stick report descriptor and more
2024-06-05 + ssd1331 driver, weak set_report_callback, some refactoring and fixes
    [keyboard_matrix.c]
2024-06-15 + macro handling, improve ws2812b driver
2024-06-25 + add kicad sch and pcb
    [KB426.kicad_pcb, KB426.kicad_sch]
2024-06-27 + update pcb
    [KB426.kicad_pcb]
2024-07-01 + update sch and pcb
    [KB426.kicad_pcb, KB426.kicad_sch]
2024-08-03 + update pcb and schematic (add led)
    [KB426.kicad_pcb, KB426.kicad_sch]
2024-08-04 + update ssd1331 footprint
2024-08-18 + ssd1331 text, refactor usb, changed hw040 to rotary encoder...
2024-09-07 update pcb (remove one led and ssd1331 spi)
    [KB426.kicad_pcb, KB426.kicad_sch]
2024-10-18 + refactoring, start usb mice support, rm macro, st7735s driver
2024-10-21 + update pcb (redo all the layout)
    [KB426.kicad_pcb, KB426.kicad_sch]
2024-10-22 + update pcb (swap right tracks layer)
    [KB426.kicad_pcb]
2024-10-23 + update pcb, usb C hack
    [KB426.kicad_pcb, KB426.kicad_sch]
2024-10-28 + update pcb (qwerty layout)
    [KB426.kicad_pcb, KB426.kicad_sch]
2024-10-29 update pcb
    [KB426.kicad_pcb]
2024-12-18 pcb v1
    [KB426.kicad_pcb, KB426.kicad_sch]
2024-12-19 little pcb fix
    [KB426.kicad_pcb]
2024-12-27 fix ground plane, update serigraphie
    [KB426.kicad_pcb, KB426.kicad_sch]
2024-12-28 pcb update
    [KB426.kicad_pcb]
2024-12-28 add easter egg
    [KB426.kicad_pcb]
2025-01-06 fix device descriptor wLength problem, fix config_descriptor wTotalLength
2025-01-11 fix ssd1306 pads size
    [KB426.kicad_pcb]
2025-01-11 fix ssd1306 gnd pad size
    [KB426.kicad_pcb]
2025-01-19 update README, deploy.sh, add macro to change leds color
2025-01-19 rename kicad project
    [Anesidora.kicad_pcb, Anesidora.kicad_sch]
2025-01-28 fix spacebar size
    [Anesidora.kicad_pcb]
2025-01-31 add mounting holes
    [Anesidora.kicad_pcb, Anesidora.kicad_sch]
